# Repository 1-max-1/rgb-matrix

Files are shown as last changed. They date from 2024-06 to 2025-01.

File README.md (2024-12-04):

# RGB Matrix
PCB and software for driving an 8x8 matrix of RGB LED's.

top_view
side_view

When digging through my pile of old electronics components I came across an LED matrix that I purchased many years ago. I was never able to get it working at the time, especially since I was using a breadboard and about a billion jumper cables (this matrix on a breadboard is an awful experience, would not recommend). I decided to try again now that I have acquired new skills and improved my old ones.

The software is a standard PlatformIO project, see the relevant folders for code. The PCB is a KiCAD project located in the `rgb-matrix-pcb` folder.

# Electronics

The circuit consists of four 8-bit shift registers chained together (along with some decoupling capacitors and resistors for the LED's). The shift registers are driven through SPI. The SPI lines are routed to a JST connector, so the PCB can communicate with a microcontroller. The first 3 shift registers control the cathodes of the R, G and B LED's. Each pin is assigned to one row. The final shift register is connected to the common anode of the LED's, with each pin assigned to one column. The matrix can then be driven with multiplexing by scanning through each column and briefly illuminating the desired rows. Persistence of Vision will take care of the rest.

Note: There are far better ways to implement this idea. There are more modern and efficient IC's that are designed specifically for this task. However, I wanted to do it my way and use the four 74hc595 shift registers because they are the same ones I tried to use on my original attempt. I wanted to finally get them working, just because I can.

I did not want to solder the matrix directly to the PCB (this turned out to be a lifesaving desicion later on), instead there are 2 rows of header pins. The matrix connects to these and sits on top of the PCB like a shield.

### The transistor board
I made a few mistakes. The biggest was that I completely overestimated the amount of current that the shift resgister pins could source and sink. For some reason I thought it would be enough to drive an entire row of LED's. I was wrong. Again, there are IC's like constant current shift registers that address this problem. Rather than redesign the PCB and wait for it to be manufactured again, I printed a little shelf with holes that fit 8 BJT's. I then did a little bit of hacky soldering so that the connection to the LED matrix is first routed to the transistors, which amplify the current before connecting back to the matrix.

# Software

The software is intended to be run on ESP32, it is untested for other boards. It uses hardware SPI to communicate with the matrix board. It operates by turning on each column of the matrix, one at a time. The desired rows for each column are then enabled. The LED's are then turned off and the cycle repeats with the next row. If done fast enough, the human eye will percieve the LED's as being constantly illuminated. One of the ESP32 hardware timers is used to control the cycle speed. With this method, brightness control can be achieved by not illuminating a row for some number of scan cycles.

Some display patterns have been programmed in, the current pattern can be cycled by activating the touch sensor on GPIO 13.

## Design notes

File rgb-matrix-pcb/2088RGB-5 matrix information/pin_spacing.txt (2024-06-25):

matrix pin rows are are 47.4 mm apart
pins are standard breadboard spacing of 2.54 mm

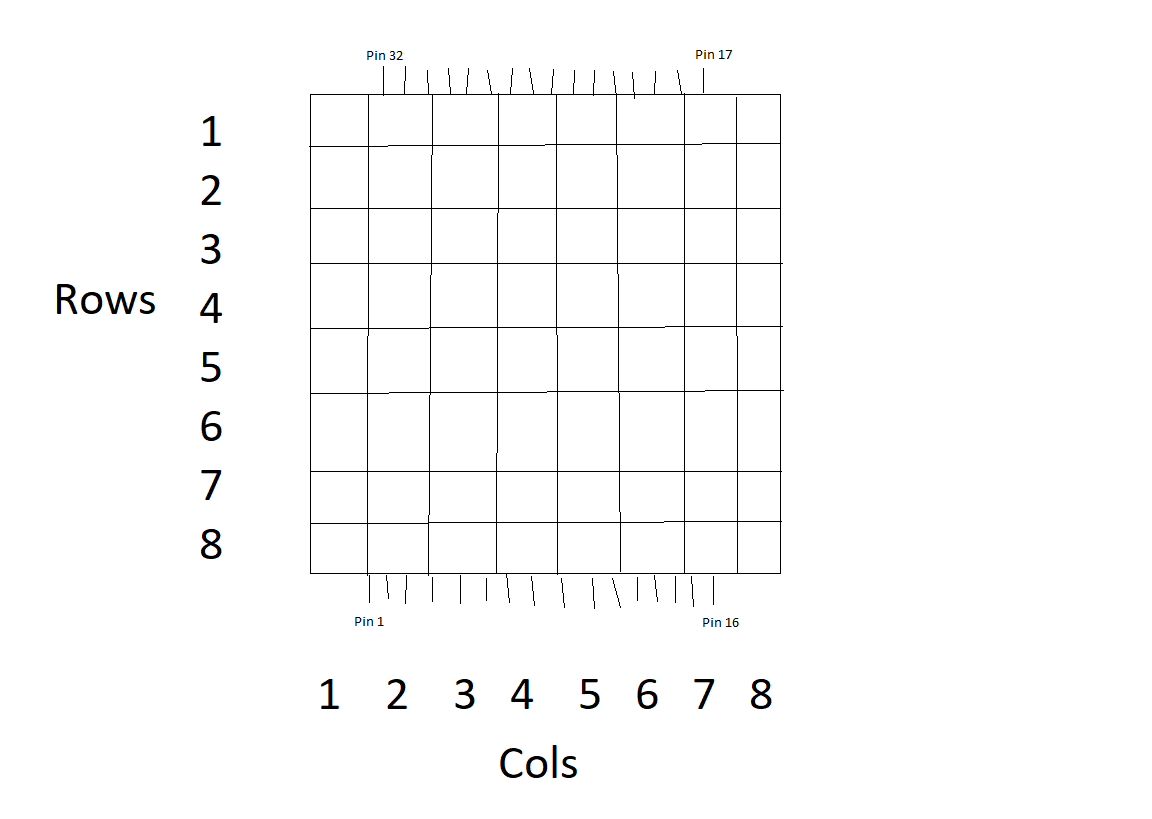
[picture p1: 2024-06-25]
rgb-matrix-pcb/2088RGB-5 matrix information/matrix_pin_locations.png

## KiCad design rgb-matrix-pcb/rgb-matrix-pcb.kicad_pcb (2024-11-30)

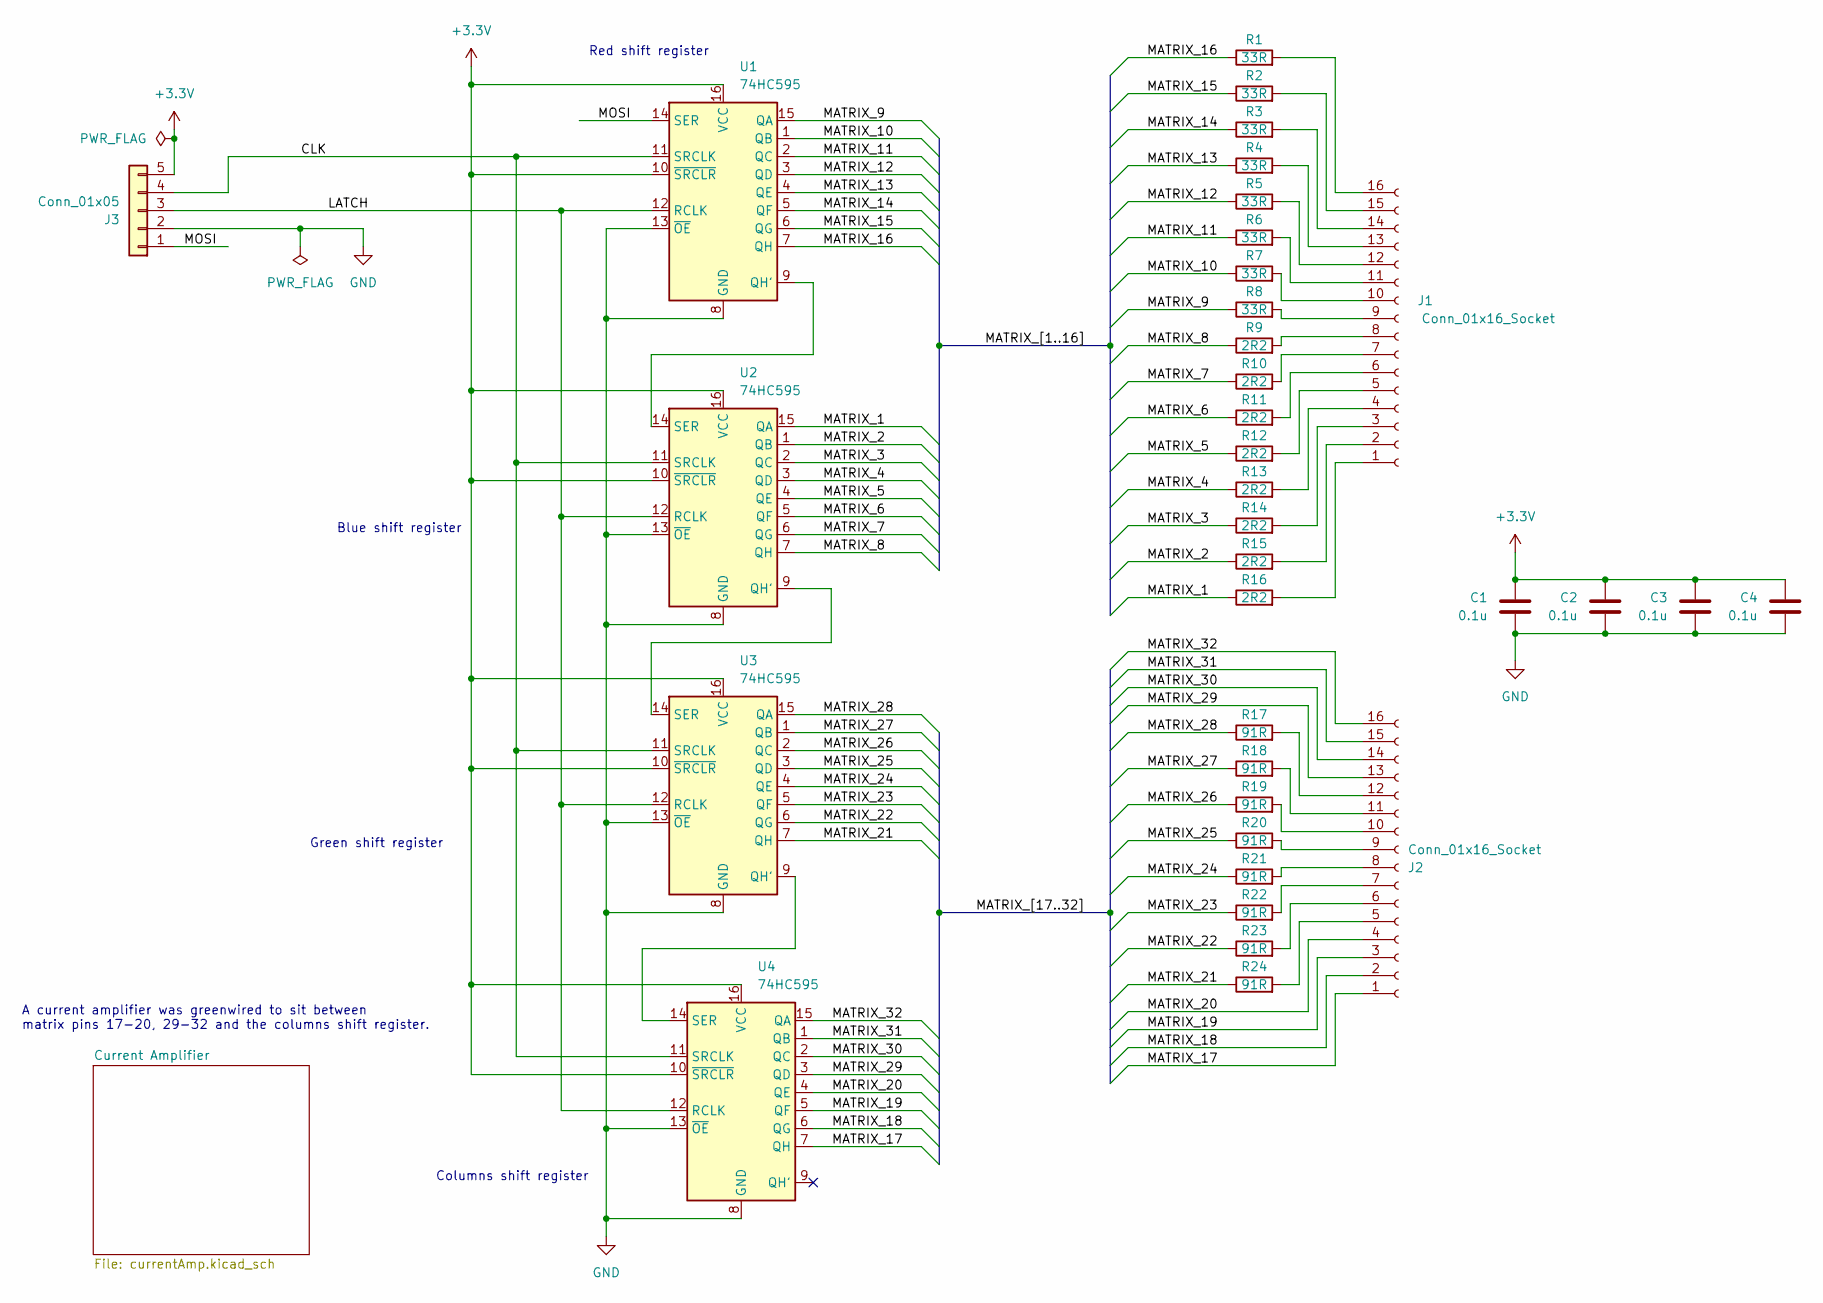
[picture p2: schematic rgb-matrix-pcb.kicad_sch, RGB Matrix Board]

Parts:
C1, C2, C3, C4: 0.1u; C_Disc_D3.4mm_W2.1mm_P2.50mm
J1, J2: Conn_01x16_Socket; PinSocket_1x16_P2.54mm_Vertical
J3: Conn_01x05; JST_PH_S5B-PH-K_1x05_P2.00mm_Horizontal
R1, R2, R3, R4, R5, R6, R7, R8: 33R; R_Axial_DIN0207_L6.3mm_D2.5mm_P7.62mm_Horizontal
R9, R10, R11, R12, R13, R14, R15, R16: 2R2; R_Axial_DIN0207_L6.3mm_D2.5mm_P7.62mm_Horizontal
R17, R18, R19, R20, R21, R22, R23, R24: 91R; R_Axial_DIN0207_L6.3mm_D2.5mm_P7.62mm_Horizontal
U1, U2, U3, U4: 74HC595; DIP-16_W7.62mm

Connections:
+3.3V: C1.2, C2.2, C3.2, C4.2, J3.5, U1.10 (~SRCLR), U1.16 (VCC), U2.10 (~SRCLR), U2.16 (VCC), U3.10 (~SRCLR), U3.16 (VCC), U4.10 (~SRCLR), U4.16 (VCC)
/CLK: J3.4, U1.11 (SRCLK), U2.11 (SRCLK), U3.11 (SRCLK), U4.11 (SRCLK)
/LATCH: J3.3, U1.12 (RCLK), U2.12 (RCLK), U3.12 (RCLK), U4.12 (RCLK)
/MATRIX_1: R16.1, U2.15 (QA)
/MATRIX_2: R15.1, U2.1 (QB)
/MATRIX_3: R14.1, U2.2 (QC)
/MATRIX_4: R13.1, U2.3 (QD)
/MATRIX_5: R12.1, U2.4 (QE)
/MATRIX_6: R11.1, U2.5 (QF)
/MATRIX_7: R10.1, U2.6 (QG)
/MATRIX_8: R9.1, U2.7 (QH)
/MATRIX_9: R8.1, U1.15 (QA)
/MATRIX_10: R7.1, U1.1 (QB)
/MATRIX_11: R6.1, U1.2 (QC)
/MATRIX_12: R5.1, U1.3 (QD)
/MATRIX_13: R4.1, U1.4 (QE)
/MATRIX_14: R3.1, U1.5 (QF)
/MATRIX_15: R2.1, U1.6 (QG)
/MATRIX_16: R1.1, U1.7 (QH)
/MATRIX_17: J2.1, U4.7 (QH)
/MATRIX_18: J2.2, U4.6 (QG)
/MATRIX_19: J2.3, U4.5 (QF)
/MATRIX_20: J2.4, U4.4 (QE)
/MATRIX_21: R24.1, U3.7 (QH)
/MATRIX_22: R23.1, U3.6 (QG)
/MATRIX_23: R22.1, U3.5 (QF)
/MATRIX_24: R21.1, U3.4 (QE)
/MATRIX_25: R20.1, U3.3 (QD)
/MATRIX_26: R19.1, U3.2 (QC)
/MATRIX_27: R18.1, U3.1 (QB)
/MATRIX_28: R17.1, U3.15 (QA)
/MATRIX_29: J2.13, U4.3 (QD)
/MATRIX_30: J2.14, U4.2 (QC)
/MATRIX_31: J2.15, U4.1 (QB)
/MATRIX_32: J2.16, U4.15 (QA)
/MOSI: J3.1, U1.14 (SER)
GND: C1.1, C2.1, C3.1, C4.1, J3.2, U1.8 (GND), U1.13 (~OE), U2.8 (GND), U2.13 (~OE), U3.8 (GND), U3.13 (~OE), U4.8 (GND), U4.13 (~OE)
unnamed: J1.1, R16.2
unnamed: J1.2, R15.2
unnamed: J1.3, R14.2
unnamed: J1.4, R13.2
unnamed: J1.5, R12.2
unnamed: J1.6, R11.2
unnamed: J1.7, R10.2
unnamed: J1.8, R9.2
unnamed: J1.9, R8.2
unnamed: J1.10, R7.2
unnamed: J1.11, R6.2
unnamed: J1.12, R5.2
unnamed: J1.13, R4.2
unnamed: J1.14, R3.2
unnamed: J1.15, R2.2
unnamed: J1.16, R1.2
unnamed: J2.5, R24.2
unnamed: J2.6, R23.2
unnamed: J2.7, R22.2
unnamed: J2.8, R21.2
unnamed: J2.9, R20.2
unnamed: J2.10, R19.2
unnamed: J2.11, R18.2
unnamed: J2.12, R17.2
unnamed: U1.9 (QH'), U2.14 (SER)
unnamed: U2.9 (QH'), U3.14 (SER)
unnamed: U3.9 (QH'), U4.14 (SER)

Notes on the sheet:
Green shift register
A current amplifier was greenwired to sit between matrix pins 17-20, 29-32 and the columns shift register.
Columns shift register
Blue shift register
Red shift register

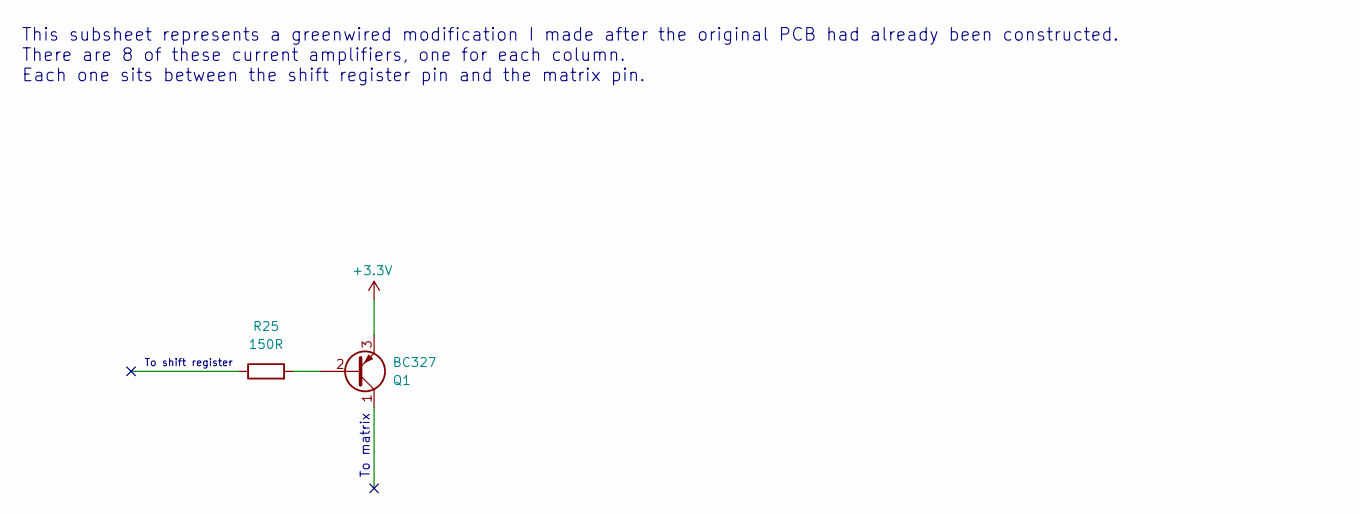
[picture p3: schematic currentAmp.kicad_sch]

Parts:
Q1: BC327; TO-92_Inline
R25: 150R

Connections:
unnamed: Q1.2 (B), R25.2

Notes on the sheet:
To matrix
This subsheet represents a greenwired modification I made after the original PCB had already been constructed. There are 8 of these current amplifiers, one for each column. Each one sits between the shift register pin and the matrix pin.
To shift register

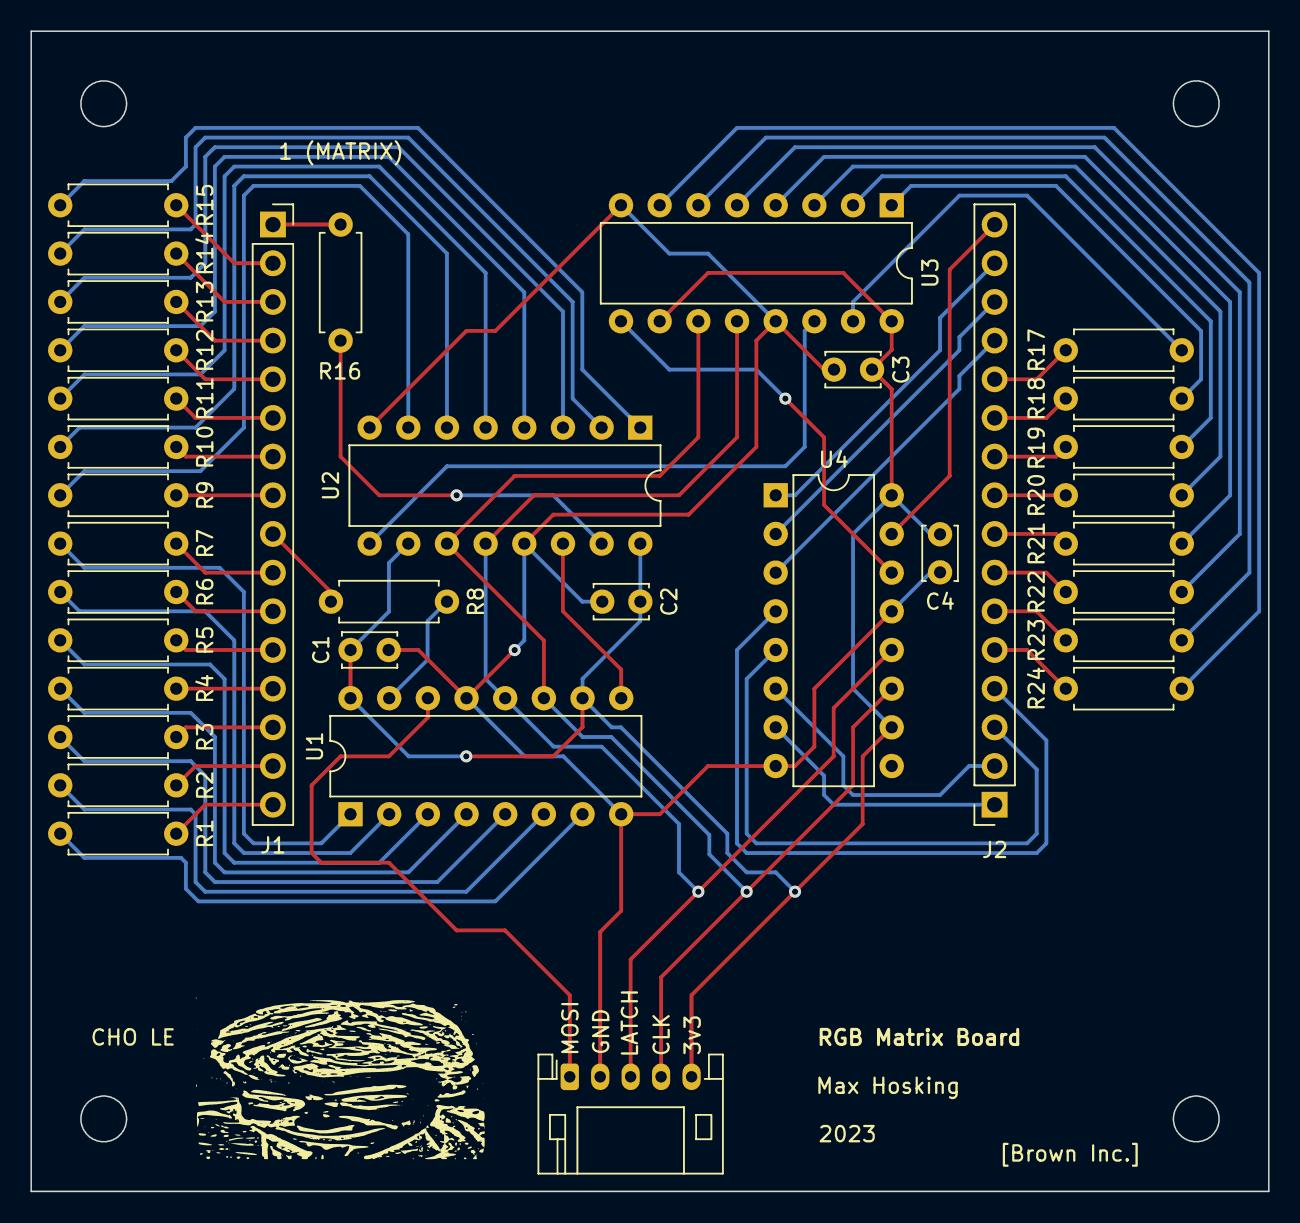
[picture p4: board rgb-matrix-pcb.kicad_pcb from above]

Board: 2 copper layers, 81.3 x 76.2 mm, 35 parts (0 on the bottom side), 64 nets.

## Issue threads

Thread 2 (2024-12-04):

Activating a LED slightly illuminates other LED's in the row.

1-max-1, 2024-12-04:
Only a minor issue. This can be seen best when activating a single red LED. For example:
```cpp
matrix.setPixel(3, 3, 31, 0, 0);
```
Turns on the correct LED. However, looking closely, all other red LED's on row 3 are just barely illuminated, when they should be completely off.

If I remove certain columns from the display scan cycle, the LED's in those columns no longer illuminate, as expected. This means that as we scan through the columns, row 3 is still "active" somehow, very briefly providing a path to ground even through the shift register should have deactivated row 3. Not sure why.

Possibly some electrical parasitic aspects, as the PCB design is pretty poor. Maybe crosstalk or self inductance is keeping the current flowing in row 3 when it shouldn't be. Saving this for later as I want to use an oscilloscope to see what's going on.

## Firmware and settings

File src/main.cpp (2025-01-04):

#include <Arduino.h>
#include <RGBMatrix.h>
#include "PatternManager.h"

// Number of ticks of duration of the the timer that updates the matrix
// See https://deepbluembedded.com/esp32-timers-timer-interrupt-tutorial-arduino-ide/
// Ensure this is not lower than the time it takes to execute the interrupt. Each call to SPI.write() is ~15 us.
const uint64_t MATRIX_TIMER_TICKS = 45; // Microseconds

/**
 * The code uses the default setup for the SPI variable, so the matrix should be wired to the default VSPI pins.
 * MOSI - 23
 * CLK - 18
 * CS/SS - 5
 */

RGBMatrix matrix;
PatternManager patterns(&matrix);

typedef void (PatternManager::*PatternFunc)();
PatternFunc patternList[6] = { &PatternManager::checker, &PatternManager::concentricSquares, &PatternManager::diagonalRainbowFade,
						&PatternManager::fullHueFade, &PatternManager::spectrumAnalyzer, &PatternManager::tiles };
uint8_t currentPatternIdx = 0;

bool touchPinActive = false;
bool lastTouchPinState = false;
const uint8_t TOUCH_THRESHOLD = 80;

void IRAM_ATTR doMatrixTick() {
	matrix.tick();
}

void setup() {
	Serial.begin(115200);

	matrix.initSPI();
	matrix.setAntiGhost(true);

	hw_timer_t* Timer0_Cfg = timerBegin(2, 80, true);
    timerAttachInterrupt(Timer0_Cfg, &doMatrixTick, true);
    timerAlarmWrite(Timer0_Cfg, MATRIX_TIMER_TICKS, true);
    timerAlarmEnable(Timer0_Cfg);
}

void loop() {
	PatternFunc currentPatternFunc = patternList[currentPatternIdx];
	(patterns.*currentPatternFunc)(); // Call update function for current pattern

	// Move to next pattern every time pin is touched
	lastTouchPinState = touchPinActive;
	touchPinActive = touchRead(13) < TOUCH_THRESHOLD;
	if (touchPinActive && !lastTouchPinState)
		currentPatternIdx = (currentPatternIdx + 1) % 6;
}

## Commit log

2024-07-05 SPI chip select now controlled by hardware
2024-11-27 Partial fix for ghosting. Slight ghosting can still ocurr but barely noticeable.
    [main.cpp]
2024-11-27 Updated to kicad 8.0
    [rgb-matrix-pcb.kicad_pcb, rgb-matrix-pcb.kicad_sch]
2024-11-29 Added basic RGB gamma correction
    [main.cpp]
2024-11-29 Updated resistor values in schematic
    [rgb-matrix-pcb.kicad_sch]
2024-11-30 Added schematic notes for greenwired current amplifiers
    [currentAmp.kicad_sch, rgb-matrix-pcb.kicad_pcb, rgb-matrix-pcb.kicad_sch]
